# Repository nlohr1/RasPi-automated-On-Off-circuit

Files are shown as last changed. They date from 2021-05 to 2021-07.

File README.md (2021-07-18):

# RasPi-automated-On-Off-circuit
Automated safe shutdown of a Raspberry Pi single-board computer.
                                  
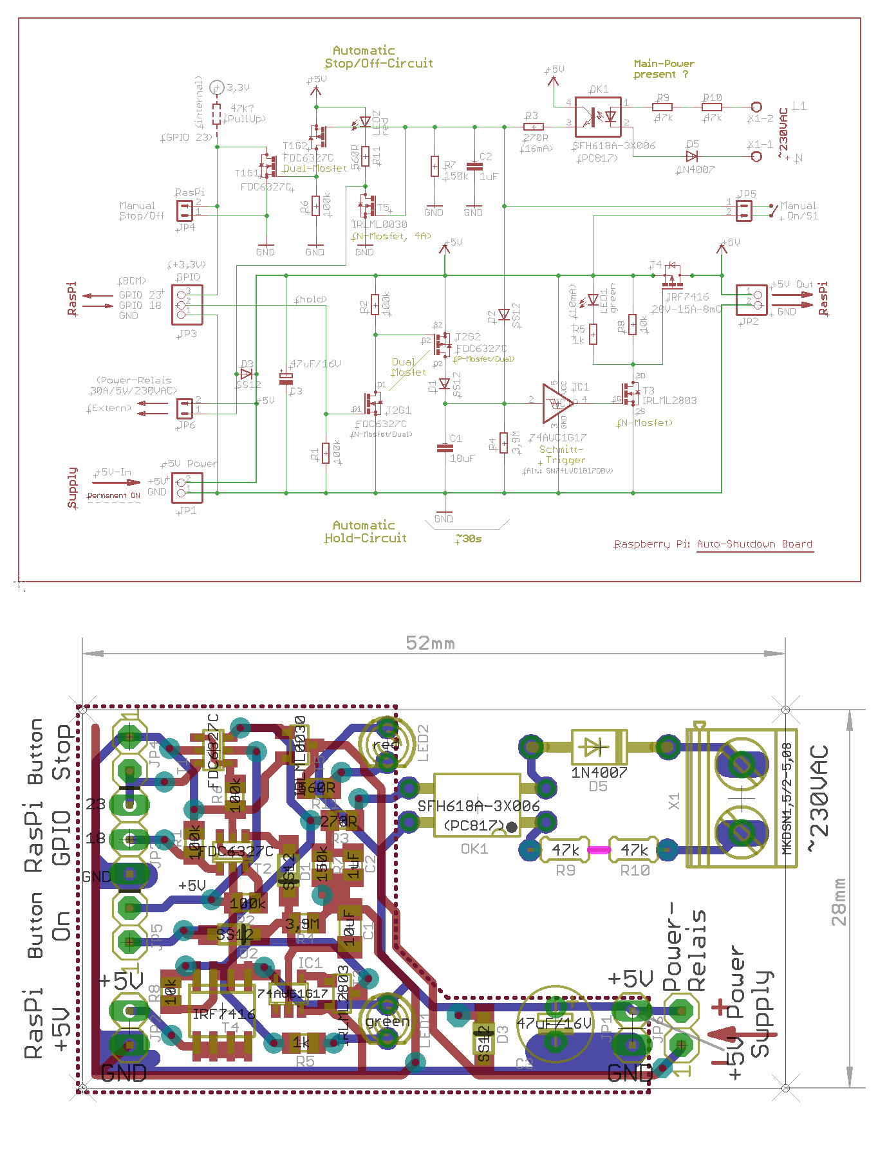
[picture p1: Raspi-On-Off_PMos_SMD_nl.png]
RasPi-automated-On-Off-circuit

**Board with soldered components (52 x 28 mm)**  

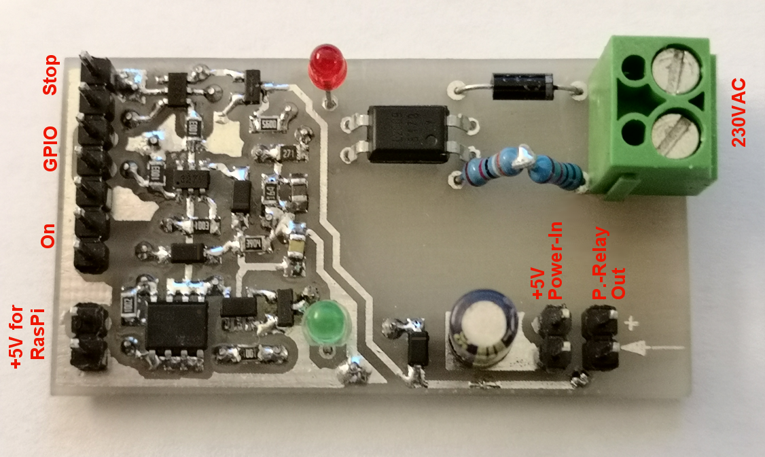
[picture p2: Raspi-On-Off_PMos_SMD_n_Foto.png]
Raspi-On-Off_PMos_SMD_n_Foto
  

This **automated** circuit acts in combination with a Python-Script (on the RasPi), shutting-off safely a Raspberry-Pi Single-Board-Computer.
Shut-off can be inizialized with a remote-controlled Switch (activated per WLAN) or with a Hardware-Button connecting one of the GPIO-Pins
of the RasPi to GND (=Ground).  
It provides the possibility to switch a concatenated Power-Relay on at startup (f.ex. to start a 3D-Printer) and a 2nd Button to manually
switch-on the 5V-Power for the RasPi (this switching "On" also the Printer-Power-Relais) and hold by the one of the GPIOs of the RasPi,
which on startup were switched high and on shutdown low.

This board is a modified copy of the work created from  
Hochschule München, FK 04, Prof. Jürgen Plate, http://www.netzmafia.de/skripten/hardware/RasPi/Projekt-OnOff/index.html

**Main attributes:**  
- integrated Schmitt-Trigger between Timing-Capacitor and Main-Switching-Mosfet,  
- detection of present Mains-Power through an optocoupler, activating the main Power-Relais (20A / 230VAC) for the machine/3D-Printer, because most
common available Remote-Switches can't **switch** safely more than a maximum of about 0,5 Amperes (~100W) - although they mostly are specified for "220V / 16A"
(= this beeing true only for the **uninterrupted** current...!).

Wiring of the System - schematic:
---------------------------------
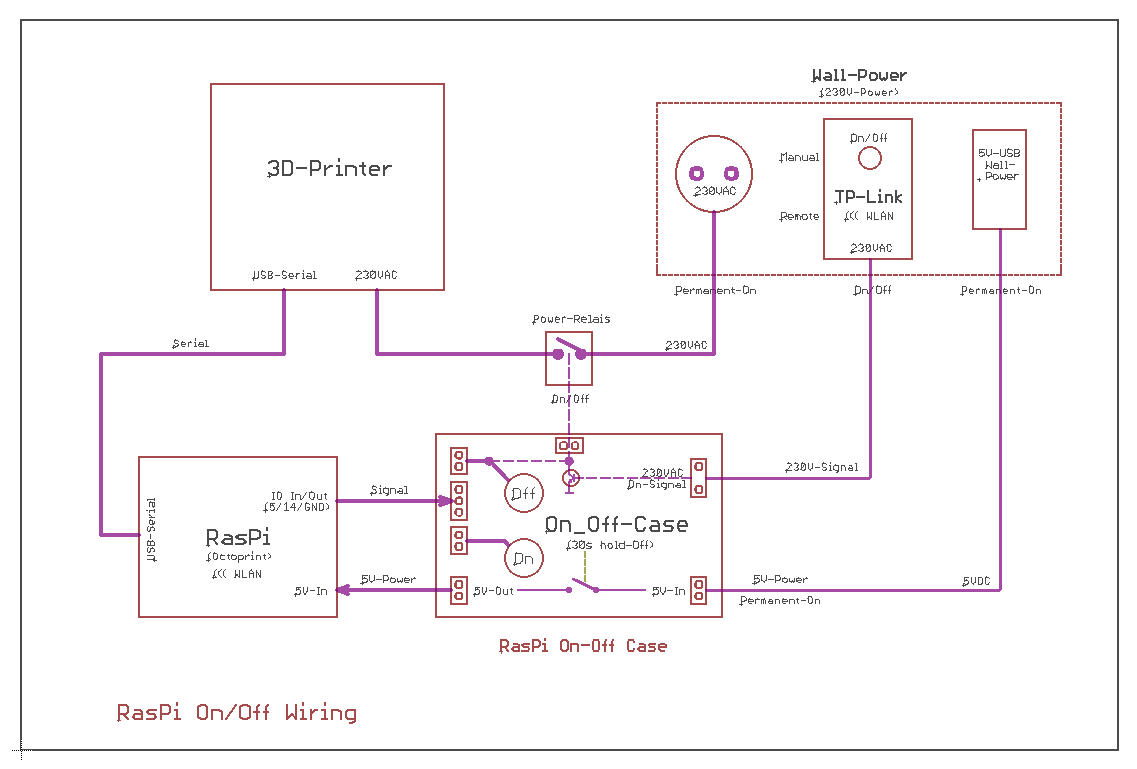
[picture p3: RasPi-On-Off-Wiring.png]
Wiring-Circuit


Preliminary remarks
-------------------
A Computer booting from a File-System needs to have a built-in **save** shutdown before turning off his (main-)power.
The Raspberry Pi alas has no buit-in safe shutdown-program nor Shutdown-Button and normally will be directly "killed" powering off.  
This abrupt "Power-Off" is default use and mostly causes no problems. But if just at this "shut-off"-moment the system is writing to the file-system
(f.ex. to the SD-Card), this may result in a (boot-)file beeing unreadable or worse in a corrupted boot-sector - and probaby next time
the system can't boot anymore – the SD-Card (the booting-system) has to be set-up again... almost much work, which can be avoided
with an additional Python-Script + a safe Shutdwon-Circuit (Hardware like this) or a simple manual Button activating the Script.
The advantage of this Circuit is it shuts the whole Power off, keeping only the small 5V/2A-(USB)-Power-Supply in StandBy-Mode.

This Shutdwon-Box acts automatically: On startup it activates a Shutdown-Routine Script on the RasPi, waiting for the Signal (or Button)
to Power-Off. This Routine (a Python-Script) can be found on many places on the internet, but mostly it isn't activated automatically
but with a manual "Shut-down" Button. To automate this process the RasPi here gets his own 5V-Supply **beeing always on**, but 
shorted off inside the circuit, so that the RasPi (yet beeing in StandBy-Mode) now is completely off.

Shut-down Signal by absence of Main-Power
-----------------------------------------
If the Main-Power (f.ex. 230VAC or 24VDC for a 3D-Printer) is shut-off (per Main-Switch or Remote-Switch), this Circuit gets the missing
Power through an Optocoupler, which signals the Raspi to run the above mentionned shutdown-script before the Circuit switches the
5V-Power-line off after a waiting-time of about 30 seconds. After that only the small USB-Power-Supply rests "On", consuming only
a few mA sensing for presence of Main-Power, and if so, the (USB) 5V-Power-line is switched on again.

Design: Mains-Power (~230VAC) on the Optocoupler!
-------
!!! ATTENTION - DANGER: Mains Power or Voltages above 40V or currents above 30mA *flowing through human body* can cause mortal heart-paralysis,
even after minutes, hours or days after a shock ocurred! So be aware of what you do, specially:
1. NEVER touch the board manually beeing "On" with connected Mains-Power! Be cautious, put the circuit in a safe box and isolate every cable
with high-voltages!
2. In (hopeful never) the case of a shock: DONT STAY ALONE, visit a doctor IN ANY CASE - if your heart stands still and you are alone - this
beeing possible also after a longer time (!) - you are definitively dead!
3. You are warned, responsibility of what you are doing with the provided circuit + files here is on to you!

Function
--------
On StartUp the Shutdown-Script sets BCM-Pin-18 (WPi GPIO-1) as Output + HIGH to signal our On-Off-Board that the Raspi is up and running.
This Signal on the Board loads and holds the Timer-Capacitor on our Circuit permanently at "full-status" (+5V) during RasPi's active-time.  
Meanwhile the +Signal from Optocoupler (HIGH) is connected to RasPi's BCM-Pin-23 (WPi GPIO-4) and is constantly monitored on background.
If LOW it activates the Shutdown-script.
After the RasPi has run the Shutdown script and is savely "down" (= in StandBy-Mode, but yet not "off"), having disconnected (unmounted)
his file-system (shutdown-routine "sudo shutdwon -h now"), his main 5V-Power-Supply may also be switched off as above mentionned. (Note:
the RasPi blinks 10 times while going down, before beeing inactive / in StandBy-Mode).
After being "down" (at the end of the Shut-Down-Script), Pin-18 is switched LOW. This LOW-Signal on the Circuit goes through Dual-Mosfet
T2 to the Timer-Capacitor (C1), which now unloads through his parallel resistance (R4: 3,9MOhm). On about ~1/3 of Voltage (after ~30s)
the connected Schmitt-Trigger switches Mosfets T3 and T4 off and so the +5V-Power line is cut-off.  
Using here a Power-Mosfet (=T4) insted of a Relay has the advantage of consuming negligible current, beeing active as well as in waiting
(StandBy-)Mode.  
If more Switching-Power is necessary (for greater loads as a small RasPi), the P-Mosfet IRF7416 (10A/20mOhm) simply may be exchanged with
a stronger type, f.ex. a IRF8736 (18A/5mO) or IRF8788 (24A/3mO), having identical packages as the IRF7416, so possible exchange without 
layout-modification. (I choosed here the IRF7416 due to good availability, but also other compatible Mosfets may be used as well).

This automated "On-Off-Switch" can be used for all Raspberry-Pi versions or also PC-Boxes, consuming upto 4 Amps (or even more) on 5VDC.  

---------------------------------------------------------------------------------------------------------------------
Add-On: Reset-Button for the Pi
-------------------------------
If in someway the RasPi went into its StandBy-Mode, we need a (Hardware-)Reset-Button to wake it up. Since Pi's boards as yet misses
Reset Buttons, nevertheless on most boards we may find a prepared via named "Run", whitch is the Pin we are looking for as Reset-Pin.
Connecting this pin to "GND" (often located directly beside) – through a Push-Button, the Raspi comes up again and so the
whole periphery as Printer, etc.  

---------------------------------------------------------------------------------------------------------------------

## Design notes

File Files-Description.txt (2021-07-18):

Files:

• Adding a Shutdown Button to the Raspberry Pi B+.txt ..... Instruction including the Python-Script and the installation on the RasPi
• Shutdown.py ............................................. Python-Script to copy to the RasPi (see Instruction above)
• Raspi-On-Off_PMos_SMD_nl.sch ............................ Eagle schematic-file of the Board
• Raspi-On-Off_PMos_SMD_nl.brd ............................ Eagle board-file of the Board
• Gerber-Files.zip ........................................ Gerber files exported to send to a PCB-Manufacturer
• Raspi-On-Off_PMos_SMD_nl.xln ............................ Excellon file for holes (SMD/TH Board), (SMD = Small-Mounted-Device / TH = ThroughHole)
• Raspi-On-Off_PMos_SMD_nl.dri ............................ Excellon description file (not really needed here)
• Raspi-On-Off_PMos_SMD_nl_Holes.nc ....................... Tanslated Excellon-holes into GRBL-Format (= ".gcode") to drill the holes first
• Raspi-On-Off_PMos_SMD_nl.png ............................ Schematic and Board on a .png-file (foreseeing the operating plan)
• Raspi-On-Off_PMos_SMD_nl_TonerDirect.pdf ................ Print-Layout for board-print with Toner-Direct-Method
• Raspi-On-Off_PMos_SMD_nl_BOM.htm ........................ BOM: Bill of Materials needed...
• Raspi-On-Off_Case_PETG.stl .............................. A proposed Case for the Board
• Raspi-On-Off_Lid_PETG.stl ............................... A proposed Case-Lid for the Board
• Raspi-On-Off_Platform.stl ............................... A proposed Case alternative (Platform without Lid)
• Raspi-On-Off_Platform.png ............................... Picture of this Platform
• Safety-casket-for-230V.stl .............................. A safety cover to cover / put over the 230VAC area (important for safety)
• Raspi-On-Off_Case.png ................................... translucent preview of the proposed Case
• Raspi-On-Off_Clip_PETG.stl .............................. Clamp of the 230VAC-Cable
• Raspi-On-Off_Clip_FR4.pdf ............................... Print-pattern for 1,5mm FR4-Material to reinforce the above printed Clamp with
• RasPi-On-Off-Wiring.sch ................................. General overview-plan of operating and connections (Eagle-schematic)
• RasPi-On-Off-Wiring.png ................................. same " " " " as above as .png picture
• RasPi-Bplus_GPIO-Pins-!.png ............................. Overview for RasPi's (newer) 40-pin GPIO Numbering...
• Power-Relais_30A-5V_SLA-05VDC.png ....................... Proposed *Power-Relais* to connect between Printer and a (WLAN) On-Off-Switch,
                                                            because most WLAN-Switches can only handle real loads with ~ < 1 Amp (230VAC)
• Platine-Case.png ........................................ On-Off Board-picture
• Cable-Holder_TPU.stl .................................... TPU-Reinforced (3D-printed) Cable-Junction between Cable-End and proposed Case
• Bild1.png - Bild6.png ................................... Fotos of first approach (later modified)

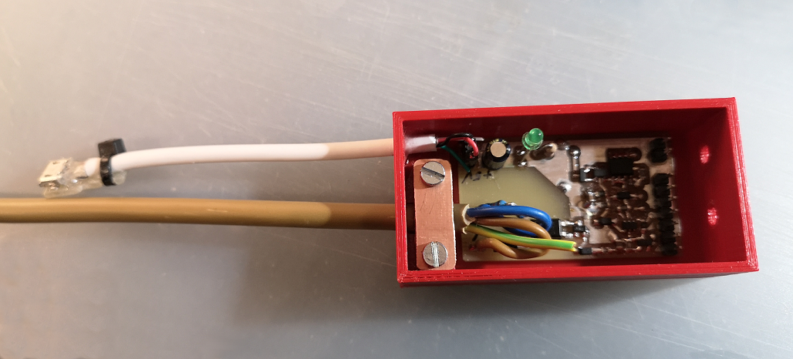
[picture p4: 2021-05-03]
Bild4.png

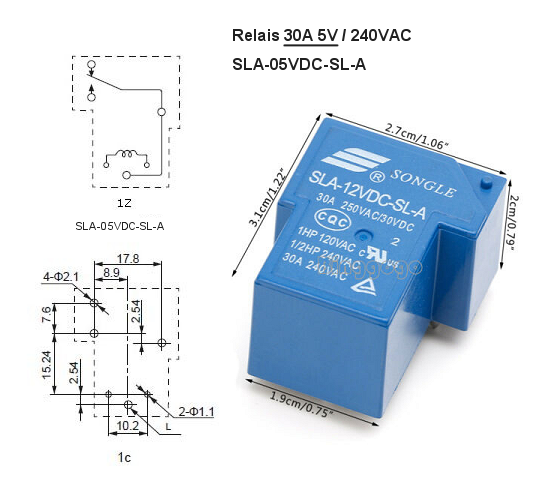
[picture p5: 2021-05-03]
Power-Relais_30A-5V_SLA-05VDC.png

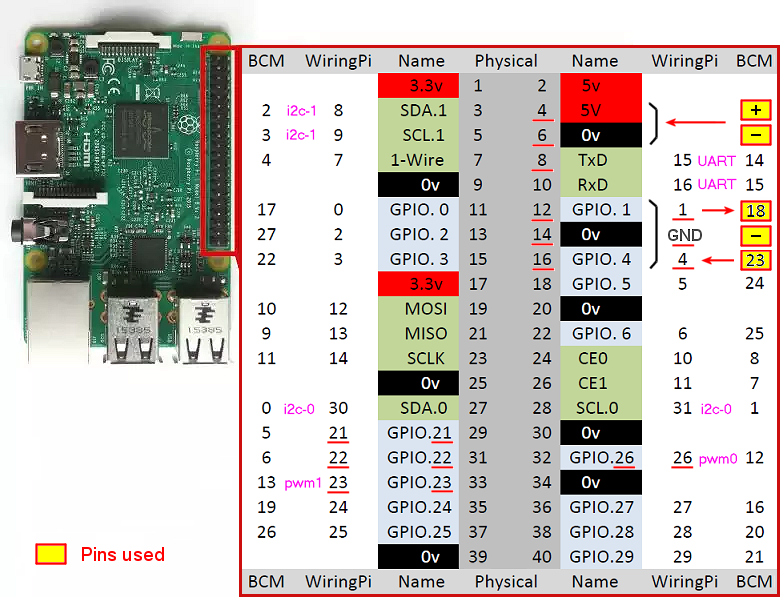
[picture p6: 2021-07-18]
RasPi-Bplus_GPIO-Pins-!.png

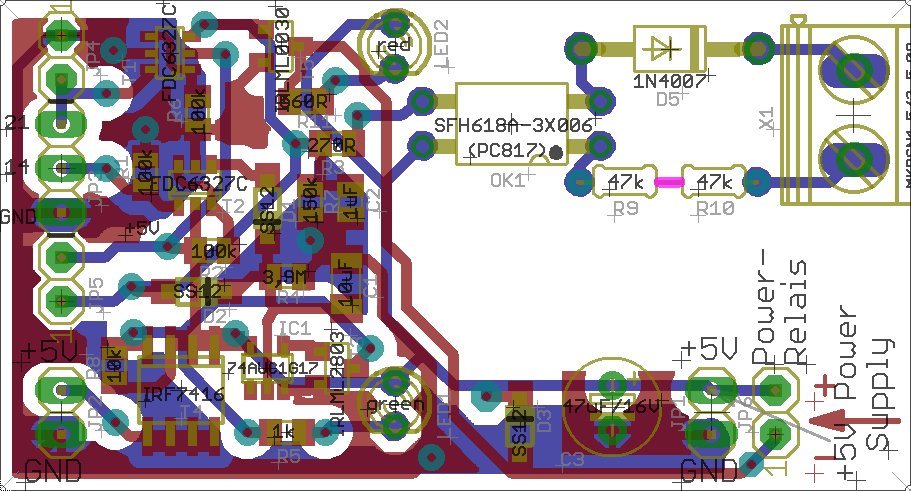
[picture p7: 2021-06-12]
Platine-Case.png

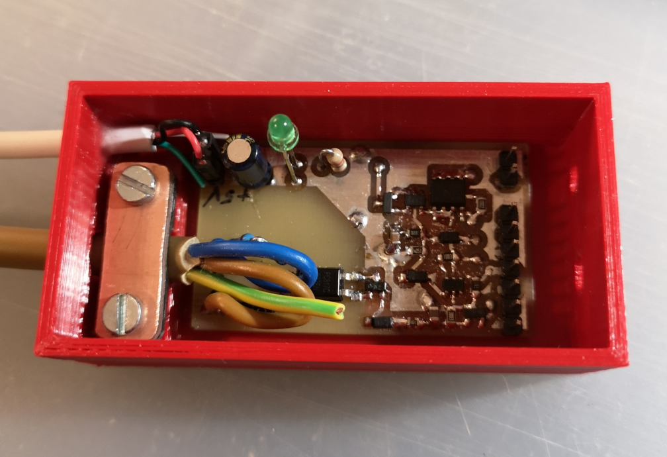
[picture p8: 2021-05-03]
Bild3.png

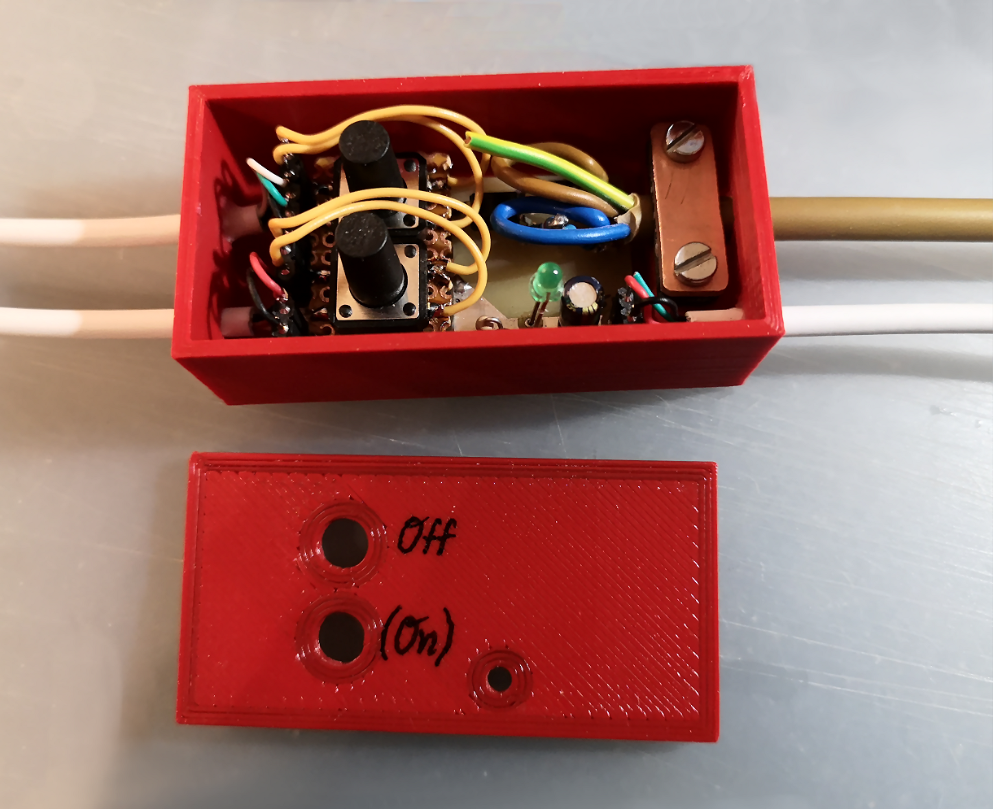
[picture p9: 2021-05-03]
Bild5.png

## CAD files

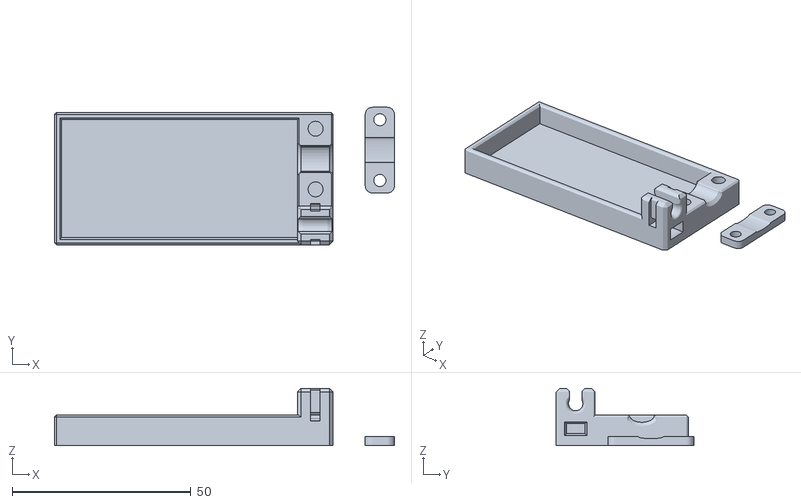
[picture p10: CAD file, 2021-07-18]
Raspi-On-Off_Platform.stl
95.2 x 38.5 x 16.0

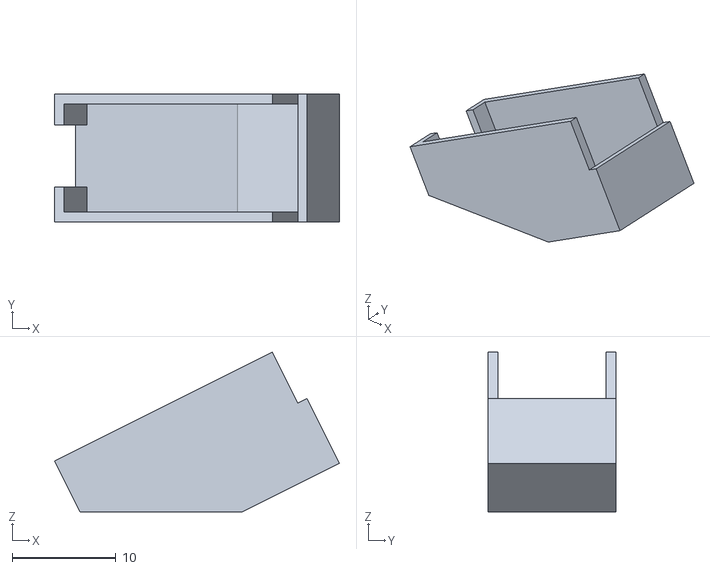
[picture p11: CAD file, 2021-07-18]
Safety-casket-for-230V.stl
27.5 x 12.4 x 15.4

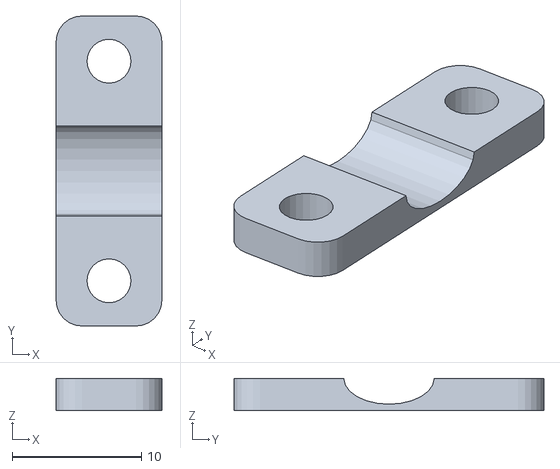
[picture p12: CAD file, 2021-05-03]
Raspi-On-Off_Clip_PETG.stl
8.20 x 24.0 x 2.50

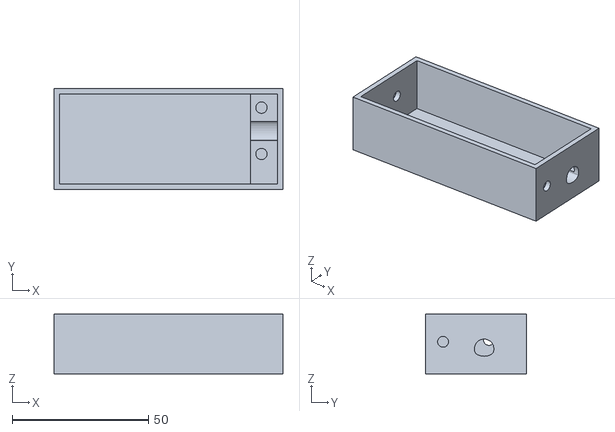
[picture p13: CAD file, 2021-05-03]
Raspi-On-Off_Case_PETG.stl
84.0 x 37.0 x 22.0

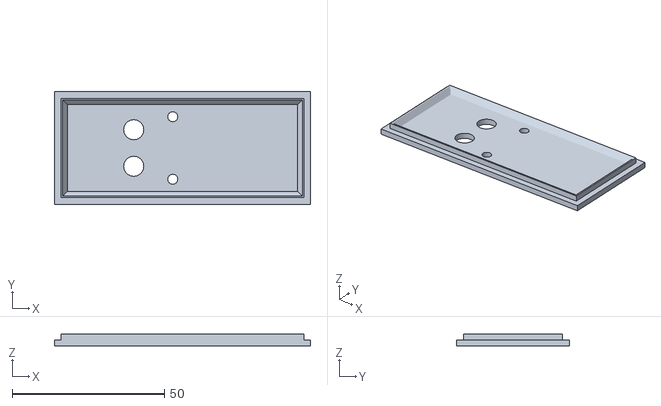
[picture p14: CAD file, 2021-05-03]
Raspi-On-Off_Lid_PETG.stl
84.0 x 37.0 x 4.00

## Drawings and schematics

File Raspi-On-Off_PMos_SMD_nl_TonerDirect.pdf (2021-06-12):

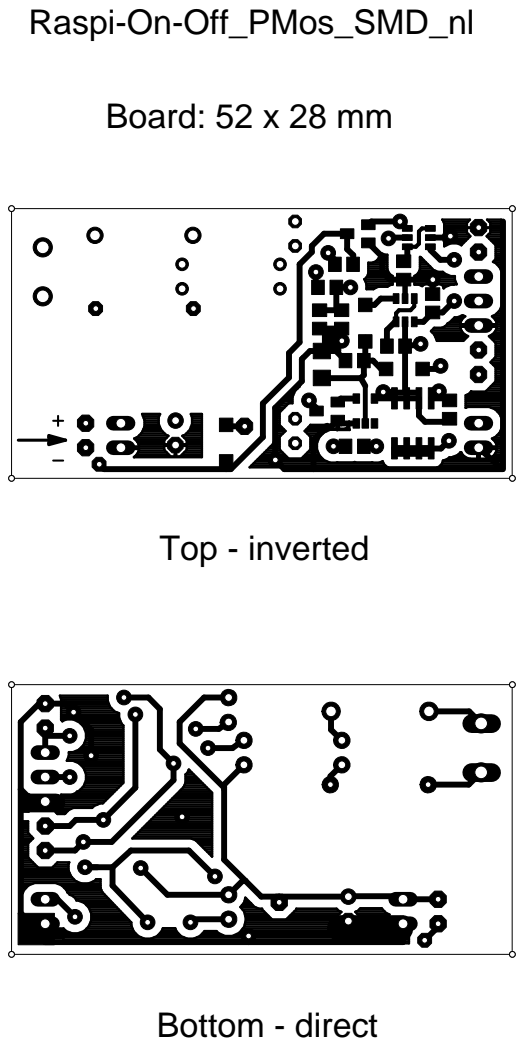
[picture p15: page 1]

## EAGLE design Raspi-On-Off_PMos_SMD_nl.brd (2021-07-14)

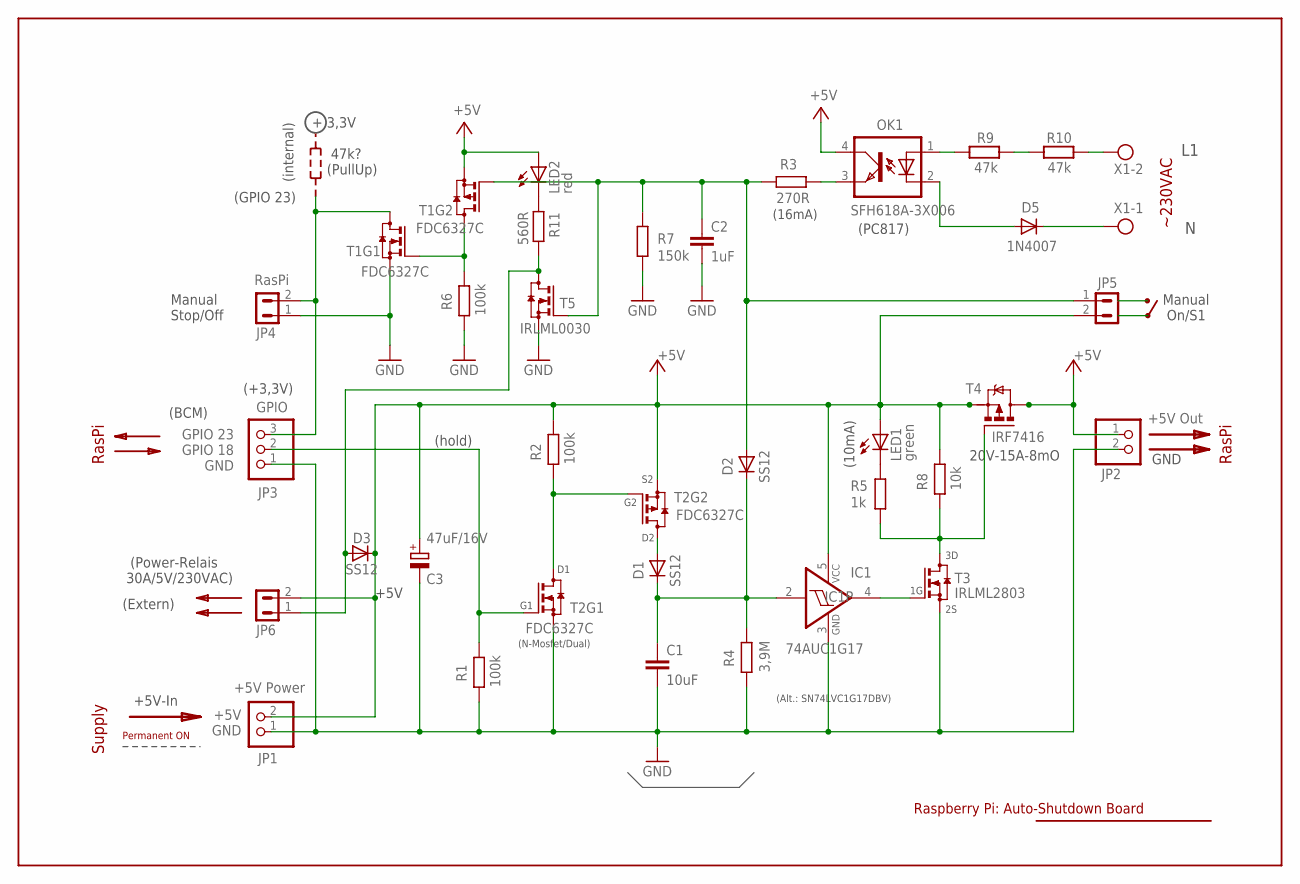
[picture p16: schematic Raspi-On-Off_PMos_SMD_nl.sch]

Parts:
C1: 10uF; C1206
C2: 1uF; C0805
C3: 47uF/16V; E2,5-6
D1, D2, D3: SS12; SOD123
D5: 1N4007; DO41-10
IC1: 74AUC1G17; SOT23-5
JP1: +5V Power; 1X02
JP2: RasPi; 1X02
JP3: GPIO; 1X03
JP4: RasPi; MA02-1R
JP5: On; MA02-1R
JP6: Relais; MA02-1R
LED1: green; LED3MM
LED2: red; LED3MM
OK1: SFH618A-3X006; DIP4-400
R1, R2, R6: 100k; R0805
R3: 270R; R0805
R4: 3,9M; R0805
R5: 1k; R0805
R7: 150k; R0805
R8: 10k; R0805
R11: 560R; R0805
T1, T2: FDC6327C; SOT23-6
T3: IRLML2803; SOT23
T4: IRF7416; SO-08
T5: IRLML0030; SOT23
X1: MKDSN1,5/2-5,08

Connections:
+5V: C3.+, D3.C, IC1.5 (VCC), JP1.2, JP5.2, JP6.2, LED1.A, LED2.A, OK1.4 (COL), R2.2, R8.2, T1.2 (S), T2.2 (S), T4.1 (S), T4.2 (S), T4.3 (S)
GND: C1.2, C2.2, C3.-, IC1.3 (GND), JP1.1, JP2.2, JP3.1, JP4.1, R1.1, R4.1, R6.1, R7.2, T1.5 (S), T2.5 (S), T3.2 (S), T5.2 (S)
unnamed: JP2.1, T4.5 (D), T4.6 (D), T4.7 (D), T4.8 (D)
unnamed: JP3.3, JP4.2, T1.6 (D)
unnamed: LED1.K (C), R5.2
unnamed: R5.1, R8.1, T3.3 (D), T4.4 (G)
unnamed: JP3.2, R1.2, T2.1 (G)
unnamed: D1.A, T2.4 (D)
unnamed: C1.1, D1.C, D2.C, IC1.2 (I), R4.2
unnamed: C2.1, D2.A, JP5.1, R3.1, R7.1, T1.3 (G), T5.1 (G)
unnamed: R2.1, T2.3 (G), T2.6 (D)
unnamed: OK1.3 (EMIT), R3.2
unnamed: R6.2, T1.1 (G), T1.4 (D)
unnamed: D5.A, OK1.2 (C)
unnamed: D5.C, X1.1
unnamed: D3.A, JP6.1, R11.1, T5.3 (D)
unnamed: LED2.K (C), R11.2
unnamed: IC1.4 (O), T3.1 (G)

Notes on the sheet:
+5V Out
+5V GND
GPIO 23 GPIO 18 GND
+5V-In
Raspberry Pi: Auto-Shutdown Board
(N-Mosfet/Dual)
(+3,3V)
Permanent ON
~230VAC
(BCM)
Manual Stop/Off
+ 3,3V
47k? (PullUp)
(internal)
(GPIO 23)
(PC817)
(hold)
20V-15A-8mO
(10mA)
(16mA)
(Power-Relais 30A/5V/230VAC)
(Extern)
(Alt.: SN74LVC1G17DBV)
RasPi
Supply
+5V
47k
R10
Manual On/S1
GND

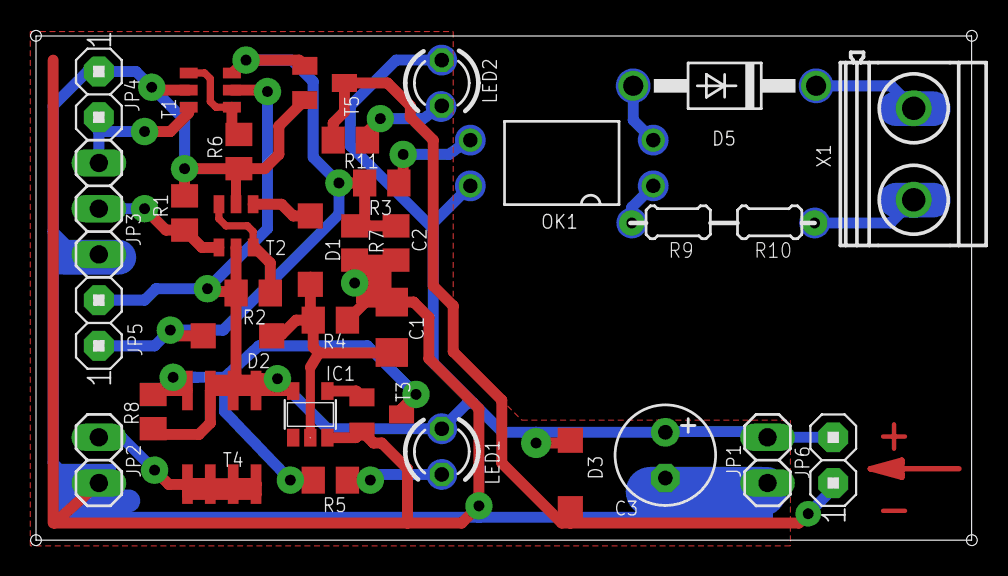
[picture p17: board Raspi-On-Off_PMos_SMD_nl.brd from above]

Board: 2 copper layers, 52.0 x 28.0 mm, 32 parts (0 on the bottom side), 18 nets.

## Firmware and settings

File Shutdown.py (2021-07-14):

# ~~~~~~~~~~~~~~~~~~~~~~~~~~~~~~~~~~~~~~~~~~~~~~~~~~~~~~~~~~~~~~~~~~~~~~~~~~~~
#!/usr/bin/python
# Simple script for shutting down the raspberry Pi at the press of a button and/or with
# the same (input-)line connected to GND per transistor, this activated by absence ("0") of
# another (external) signal as beeing a 230V-Sensor (optocoupler) or a signal from RasPi,
# activated from Octoprint as GPIO-line.

import RPi.GPIO as GPIO
import time
import os

# Use the Broadcom SOC Pin numbers "BCM",
# Setup the Pins with internal pullups enabled, PIN-23 (BCM) as input in reading mode, and
# PIN-18 as Output, to use as Signal for the On-Off-Board indicating the Pi is up and running:
GPIO.setmode(GPIO.BCM)
GPIO.setup(18, GPIO.OUT, pull_up_down = GPIO.PUD_UP) # set BCM 18 (GPIO 1) as Output and high.
GPIO.setup(23, GPIO.IN, pull_up_down = GPIO.PUD_UP)  # set BCM 23 (GPIO 4) as Input with internal pull-Up R's.

# Our function on *what to do* after the Shutdown-Button is pressed (=connected to GND), or
# automatically (here default), when the Optocoupler sets this line to GND - in absence of Main-Power:
def Shutdown(channel):
  GPIO.output(18, GPIO.LOW) # LOW on Pin-18 terminates the constant-charge of the Timing-Capacitor!
  os.system("sudo shutdown -h now")

# Sensing "button-pressed?":
# Add our Shutdown function to execute when the "button pressed" event (on Pin-23) happens:
GPIO.add_event_detect(23, GPIO.FALLING, callback = Shutdown, bouncetime = 2000)

# Now wait:
while 1:
  time.sleep(100)
# ~~~~~~~~~~~~~~~~~~~~~~~~~~~~~~~~~~~~~~~~~~~~~~~~~~~~~~~~~~~~~~~~~~~~~~~~~~~~
